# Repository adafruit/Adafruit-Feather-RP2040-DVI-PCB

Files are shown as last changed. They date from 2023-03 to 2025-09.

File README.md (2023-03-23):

## Adafruit Feather RP2040 DVI PCB

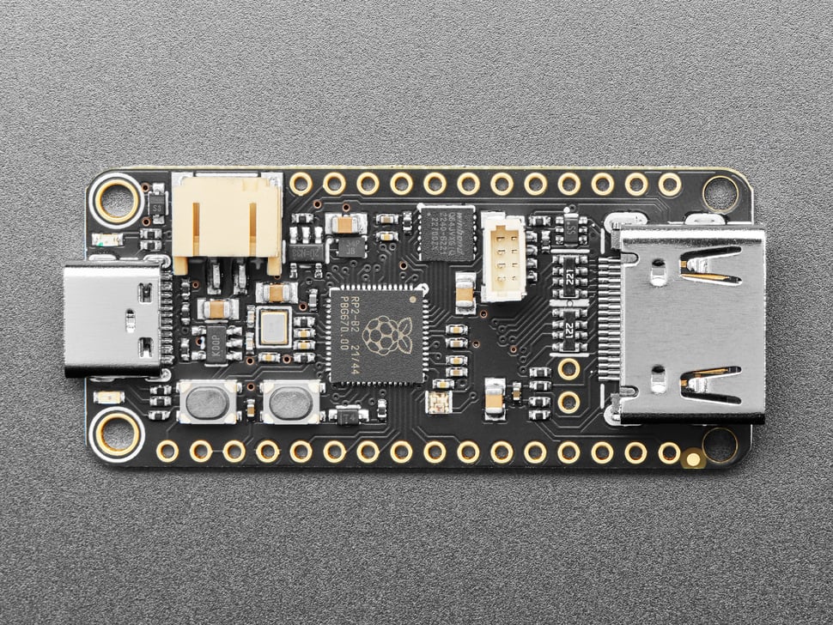
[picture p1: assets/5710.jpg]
<a href="http://www.adafruit.com/products/5710"><br/>
Click here to purchase one from the Adafruit shop</a>

PCB files for the Adafruit Feather RP2040 DVI. 

Format is EagleCAD schematic and board layout
* https://www.adafruit.com/product/5710

### Description

Wouldn't it be cool if you could display images and graphics from a microcontroller directly to an HDMI monitor or television? We think so! So we designed this RP2040 Feather that has a digital video output (a.k.a DVI) that will work with any HDMI monitor or display. Note it doesn't do audio, just graphics!

It's kinda like we took our RP2040 Feather and DVI Breakout board and glued them together. You get all the pins for use on the Feather, the Lipoly battery support, USB C power / data, onboard NeoPixel, 8MB of FLASH for storing code and files, and then with the 8 unused pins, a DVI output that can be used with the PicoDVI library in Arduino or Pico SDK (note we don't have Circuitpython support for DVI output at this time)

In Arduino, which is what we recommend, we use our fork of PicoDVI to create an internal framebuffer of 320x240 or 400x240 16-bit pixels that is then continuously blitted out as pixel-doubled 640x480 or 800x480 digital video. Whatever you 'draw' to the internal memory framebuffer appears instantly on the digital display in crisp color. Since the library is a subclass of AdafruitGFX, it'll be familiar to folks who have used our TFT or OLED displays before.

Note that the DVI video generation uses one full core, both PIOs, and 150K (320x240) or 190K (400x240) of SRAM. It's kinda maxed out so be aware of the remaining resource limitations.

We also connected the HDMI-connectors I2C pins to the SDA/SCL of the Feather (through a safe level shifter) so you can read the EDID EEPROM of displays, and have broken out the CEC and Utility pads. The Hot Plug Detect pin is also available on the very end of the 16-pin header. Read this pin to know when a display has been connected!

### License

Adafruit invests time and resources providing this open source design, please support Adafruit and open-source hardware by purchasing products from [Adafruit](https://www.adafruit.com)!

Designed by Limor Fried/Ladyada for Adafruit Industries.

Creative Commons Attribution/Share-Alike, all text above must be included in any redistribution. 
See license.txt for additional details.

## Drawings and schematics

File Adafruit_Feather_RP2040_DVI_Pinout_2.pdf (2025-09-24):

# Adafruit Feather RP2040 DVI

# https://www.adafruit.com/product/5710

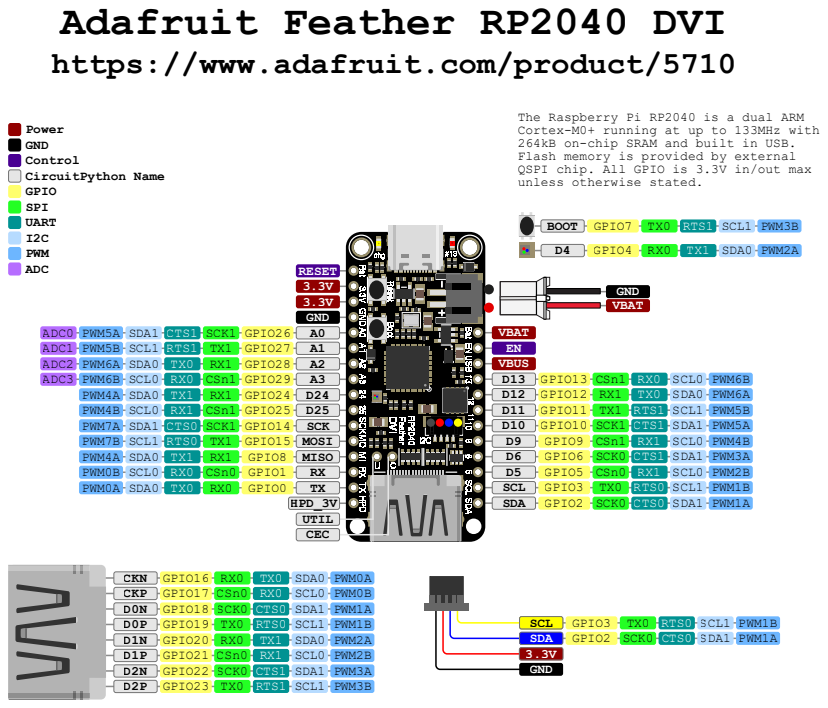
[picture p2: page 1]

The Raspberry Pi RP2040 is a dual ARM
Cortex-M0+ running at up to 133MHz with
264kB on-chip SRAM and built in USB.
Flash memory is provided by external
QSPI chip. All GPIO is 3.3V in/out max
unless otherwise stated.

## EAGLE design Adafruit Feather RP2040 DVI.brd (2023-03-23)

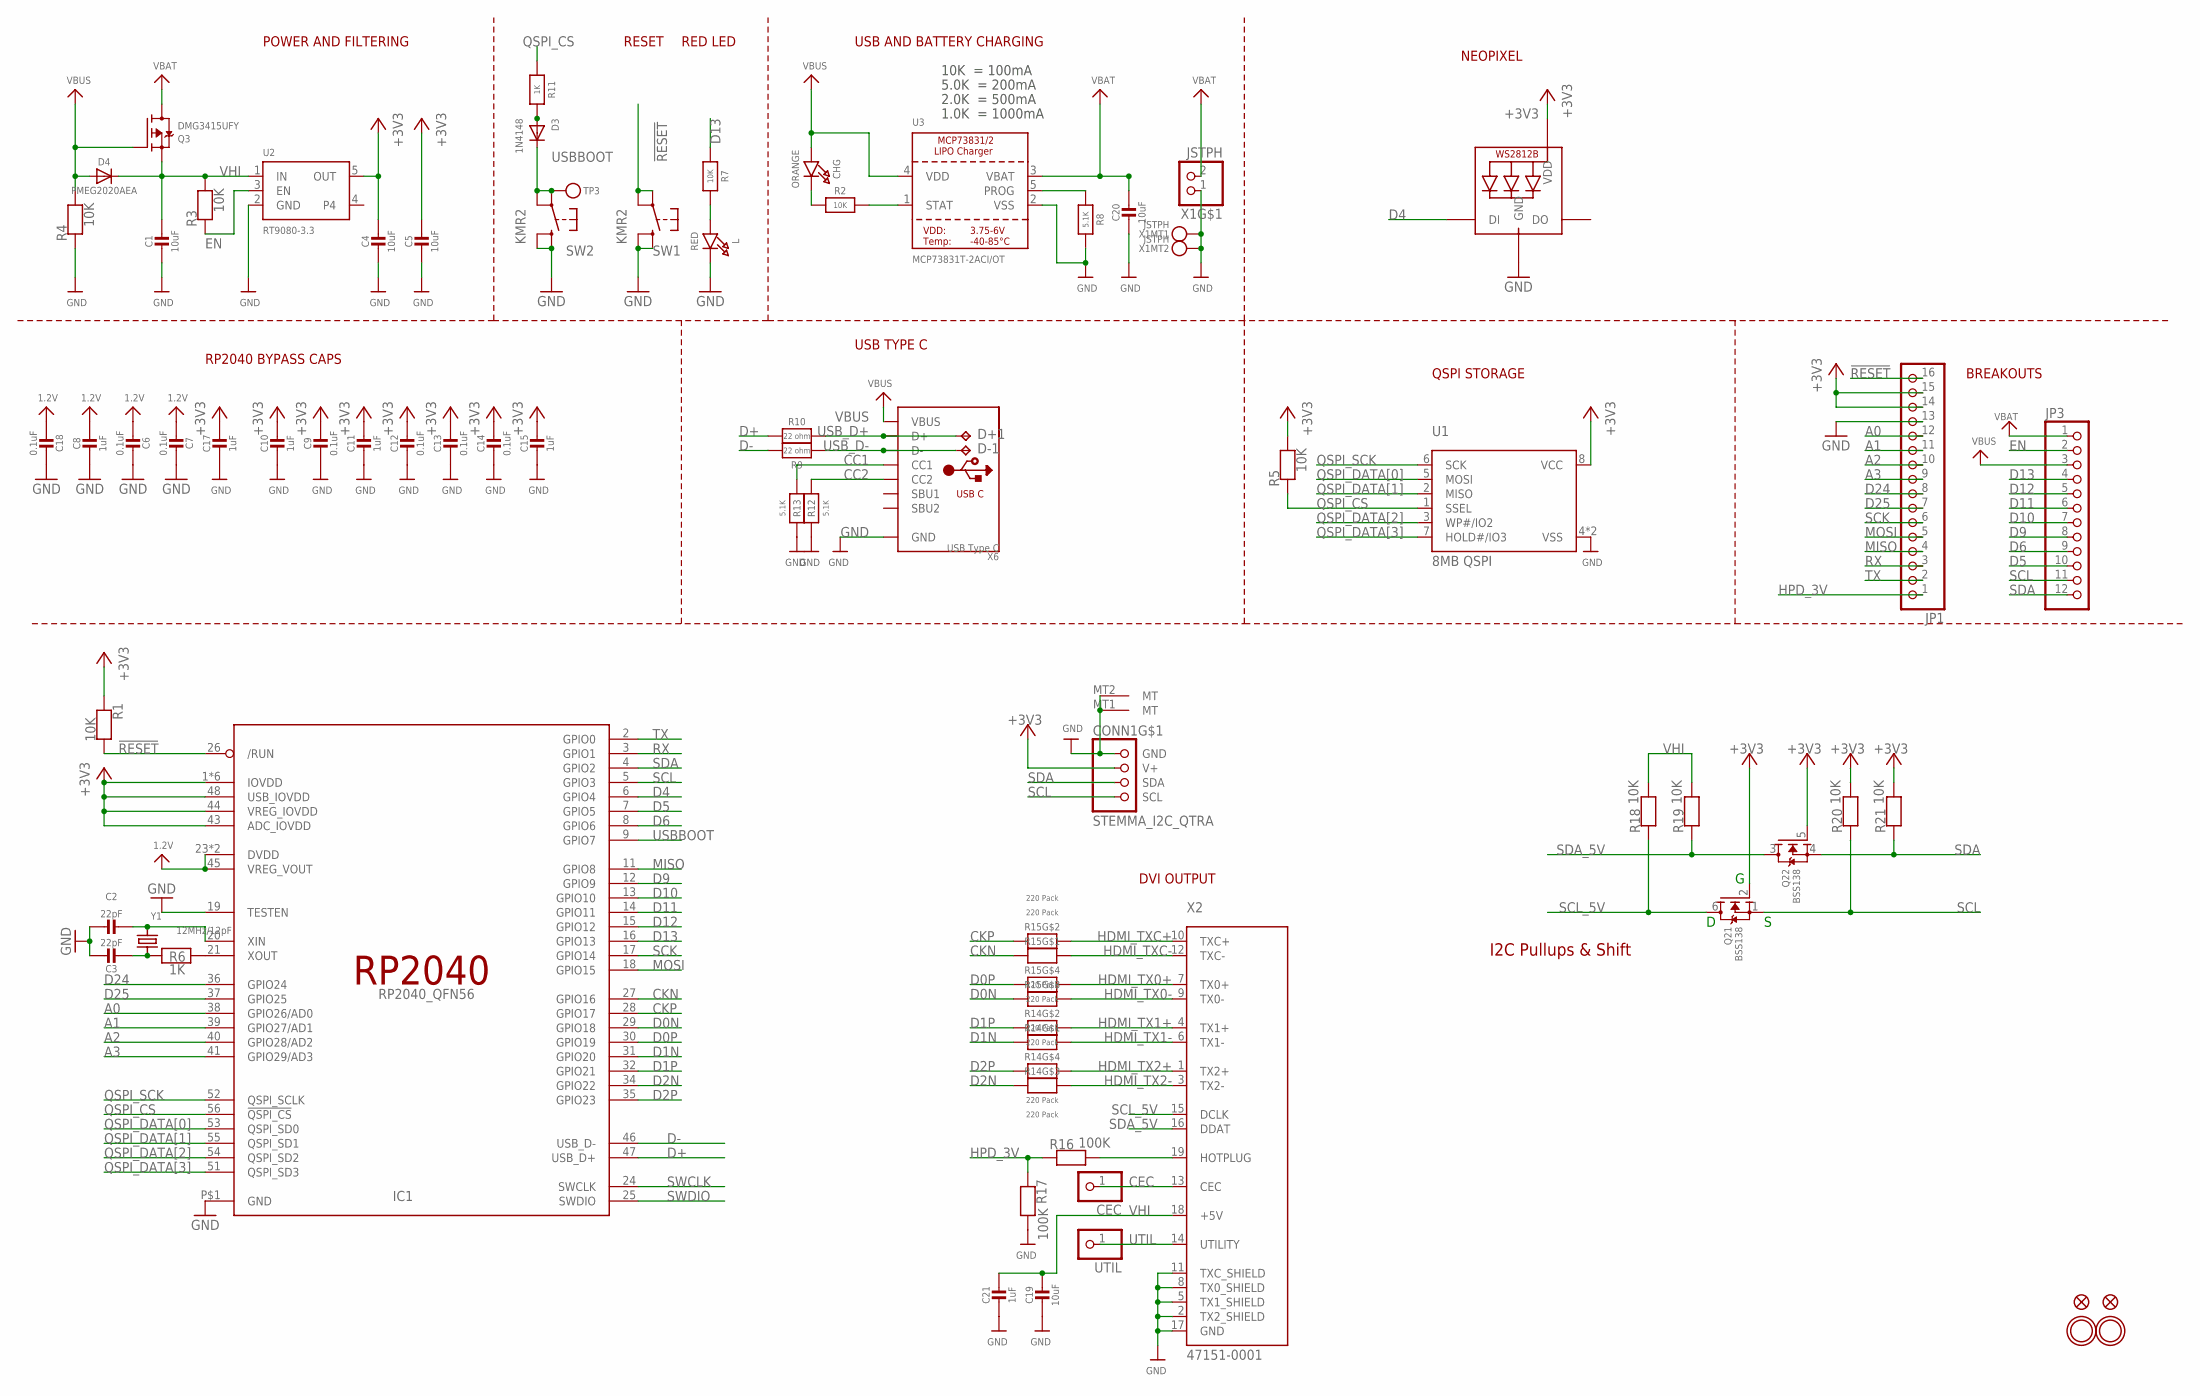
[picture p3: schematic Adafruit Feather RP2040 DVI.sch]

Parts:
C1, C4, C5, C19, C20: 10uF; 0805-NO
C2, C3: 22pF; _0402NO
C6, C7, C9, C12, C13, C14, C18: 0.1uF; _0402NO
C8, C10, C11, C15, C17, C21: 1uF; _0402NO
CEC: HEADER-1X1ROUND; 1X01_ROUND
CHG: ORANGE; CHIPLED_0603_NOOUTLINE
CONN1: STEMMA_I2C_QTRA; JST_SH4_RA
D3: 1N4148; SOD-323F
D4: PMEG2020AEA; SOD-323F
D+1: TPB1,27; B1,27
D-1: TPB1,27; B1,27
IC1: RP2040_QFN56; QFN56_7MM_REDUCEDEPAD
JP1: HEADER-1X16ROUND; 1X16_ROUND
JP3: HEADER-1X12; 1X12_ROUND
L: RED; CHIPLED_0603_NOOUTLINE
LED1: WS2812B_SK6805_1515; SK6805_1515
Q2: BSS138; SOT363
Q3: DMG3415UFY; DFN2015-3
R1, R2, R3, R4, R5, R7, R18, R19, R20, R21: 10K; _0402NO
R6, R11: 1K; _0402NO
R8, R12, R13: 5.1K; _0402NO
R9, R10: 22 ohm; _0402NO
R14, R15: 220 Pack; RESPACK_4X0603
R16, R17: 100K; _0402NO
SW1, SW2: KMR2; BTN_RKB2_4.6X2.8
TP3: TESTPOINTROUND1.5MMNO; TESTPOINT_ROUND_1.5MM_NO
U1: 8MB QSPI; USON8_4X4
U2: RT9080-3.3; SOT23-5; JLC_ROTATION 0
U3: MCP73831T-2ACI/OT; SOT23-5
U$31, U$32: MOUNTINGHOLE2.5; MOUNTINGHOLE_2.5_PLATED
U$34, U$35: FIDUCIAL_1MM
UTIL: HEADER-1X1ROUND; 1X01_ROUND
X1: JSTPH; JSTPH2_BATT
X2: 47151-0001; HDMI_MOLEX_47151-0001
X6: USB Type C; USB_C_CUSB31-CFM2AX-01-X
Y1: 12MHz/12pF; CRYSTAL_2.5X2

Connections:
1.2V: C6.2, C7.2, C8.1, C18.2, IC1.23 (DVDD), IC1.45 (VREG_VOUT), IC1.50 (DVDD)
!RESET: IC1.26 (/RUN), JP1.16, R1.2, SW1.A, SW1.A' (P1)
+3V3: C4.1, C5.1, C9.1, C10.1, C11.1, C12.1, C13.1, C14.1, C15.1, C17.1, CONN1.2 (V+), IC1.1 (IOVDD), IC1.10 (IOVDD), IC1.22 (IOVDD), IC1.33 (IOVDD), IC1.42 (IOVDD), IC1.43 (ADC_IOVDD), IC1.44 (VREG_IOVDD), IC1.48 (USB_IOVDD), IC1.49 (IOVDD), JP1.14, JP1.15, LED1.2 (VDD), Q2.2 (G), Q2.5 (G), R1.1, R5.2, R20.2, R21.2, U1.8 (VCC), U2.5 (OUT)
A0: IC1.38 (GPIO26/AD0), JP1.12
A1: IC1.39 (GPIO27/AD1), JP1.11
A2: IC1.40 (GPIO28/AD2), JP1.10
A3: IC1.41 (GPIO29/AD3), JP1.9
CC1: R13.2, X6.A5 (CC1)
CC2: R12.2, X6.B5 (CC2)
CEC: CEC.1, X2.13 (CEC)
CKN: IC1.27 (GPIO16), R15.8 (2)
CKP: IC1.28 (GPIO17), R15.7 (2)
D0N: IC1.29 (GPIO18), R15.6 (2)
D0P: IC1.30 (GPIO19), R15.5 (2)
D1N: IC1.31 (GPIO20), R14.8 (2)
D1P: IC1.32 (GPIO21), R14.7 (2)
D2N: IC1.34 (GPIO22), R14.6 (2)
D2P: IC1.35 (GPIO23), R14.5 (2)
D4: IC1.6 (GPIO4), LED1.1 (DI)
D5: IC1.7 (GPIO5), JP3.10
D6: IC1.8 (GPIO6), JP3.9
D9: IC1.12 (GPIO9), JP3.8
D10: IC1.13 (GPIO10), JP3.7
D11: IC1.14 (GPIO11), JP3.6
D12: IC1.15 (GPIO12), JP3.5
D13: IC1.16 (GPIO13), JP3.4, R7.1
D24: IC1.36 (GPIO24), JP1.8
D25: IC1.37 (GPIO25), JP1.7
D+: IC1.47 (USB_D+), R10.2
D-: IC1.46 (USB_D-), R9.2
EN: JP3.2, R3.1, U2.3 (EN)
GND: C1.2, C2.1, C3.1, C4.2, C5.2, C6.1, C7.1, C8.2, C9.2, C10.2, C11.2, C12.2, C13.2, C14.2, C15.2, C17.2, C18.1, C19.2, C20.2, C21.2, CONN1.1 (GND), CONN1.MT1 (MT), CONN1.MT2 (MT), IC1.19 (TESTEN), IC1.P$1 (GND), JP1.13, L.C, LED1.4 (GND), R4.1, R8.2, R12.1, R13.1, R17.2, SW1.B (S), SW1.B' (S1), SW2.B (S), SW2.B' (S1), U1.4 (VSS), U1.PAD (VSS), U2.2 (GND), U3.2 (VSS), X1.1, X1.NC1, X1.NC2, X2.2 (TX2_SHIELD), X2.5 (TX1_SHIELD), X2.8 (TX0_SHIELD), X2.11 (TXC_SHIELD), X2.17 (GND), X2.P$1 (GND), X2.P$2 (GND), X2.P$3 (GND), X2.P$4 (GND), X6.A1B12 (GND), X6.B1A12 (GND)
HDMI_TX0+: R15.4 (1), X2.7 (TX0+)
HDMI_TX0-: R15.3 (1), X2.9 (TX0-)
HDMI_TX1+: R14.2 (1), X2.4 (TX1+)
HDMI_TX1-: R14.1, X2.6 (TX1-)
HDMI_TX2+: R14.4 (1), X2.1 (TX2+)
HDMI_TX2-: R14.3 (1), X2.3 (TX2-)
HDMI_TXC+: R15.2 (1), X2.10 (TXC+)
HDMI_TXC-: R15.1, X2.12 (TXC-)
HPD: R16.2, X2.19 (HOTPLUG)
HPD_3V: JP1.1, R16.1, R17.1
MISO: IC1.11 (GPIO8), JP1.4
MOSI: IC1.18 (GPIO15), JP1.5
unnamed: CHG.C, R2.1
unnamed: L.A, R7.2
unnamed: R2.2, U3.1 (STAT)
unnamed: R8.1, U3.5 (PROG)
unnamed: C2.2, IC1.20 (XIN), Y1.3 (2)
unnamed: C3.2, R6.1, Y1.1
unnamed: IC1.21 (XOUT), R6.2
unnamed: D3.A, R11.2
QSPI_CS: IC1.56 (!QSPI_CS), R5.1, R11.1, U1.1 (SSEL)
QSPI_DATA[0]: IC1.53 (QSPI_SD0), U1.5 (MOSI)
QSPI_DATA[1]: IC1.55 (QSPI_SD1), U1.2 (MISO)
QSPI_DATA[2]: IC1.54 (QSPI_SD2), U1.3 (WP#/IO2)
QSPI_DATA[3]: IC1.51 (QSPI_SD3), U1.7 (HOLD#/IO3)
QSPI_SCK: IC1.52 (QSPI_SCLK), U1.6 (SCK)
RX: IC1.3 (GPIO1), JP1.3
SCK: IC1.17 (GPIO14), JP1.6
SCL: CONN1.4 (SCL), IC1.5 (GPIO3), JP3.11, Q2.1 (S), R20.1
SCL_5V: Q2.6 (D), R18.1, X2.15 (DCLK)
SDA: CONN1.3 (SDA), IC1.4 (GPIO2), JP3.12, Q2.4 (S), R21.1
SDA_5V: Q2.3 (D), R19.1, X2.16 (DDAT)
SWCLK: IC1.24 (SWCLK)
SWDIO: IC1.25 (SWDIO)
TX: IC1.2 (GPIO0), JP1.2
USBBOOT: D3.C, IC1.9 (GPIO7), SW2.A, SW2.A' (P1), TP3.P$1
USB_D+: D+1.TP, R10.1, X6.A6 (D+), X6.B6 (D+)
USB_D-: D-1.TP, R9.1, X6.A7 (D-), X6.B7 (D-)
UTIL: UTIL.1, X2.14 (UTILITY)
VBAT: C20.1, JP3.1, Q3.3 (D), U3.3 (VBAT), X1.2
VBUS: CHG.A, D4.A, JP3.3, Q3.1 (G), R4.2, U3.4 (VDD), X6.A4B9 (VBUS), X6.B4A9 (VBUS)
VHI: C1.1, C19.1, C21.1, D4.C, Q3.2 (S), R3.2, R18.2, R19.2, U2.1 (IN), X2.18 (+5V)

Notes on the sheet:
POWER AND FILTERING
RESET
10K = 100mA
5.0K = 200mA
2.0K = 500mA
1.0K = 1000mA
USB AND BATTERY CHARGING
BREAKOUTS
RED LED
DVI OUTPUT
RP2040 BYPASS CAPS
USB TYPE C
QSPI STORAGE
NEOPIXEL
I2C Pullups & Shift

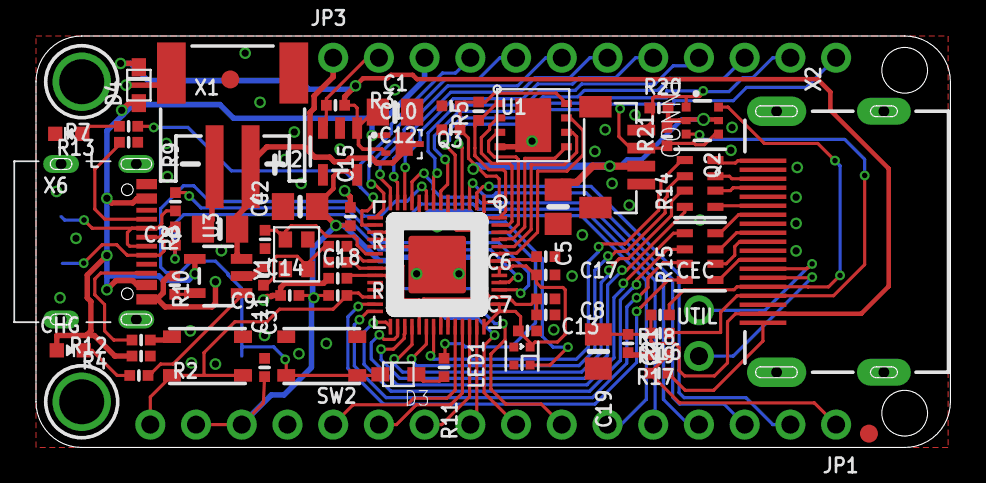
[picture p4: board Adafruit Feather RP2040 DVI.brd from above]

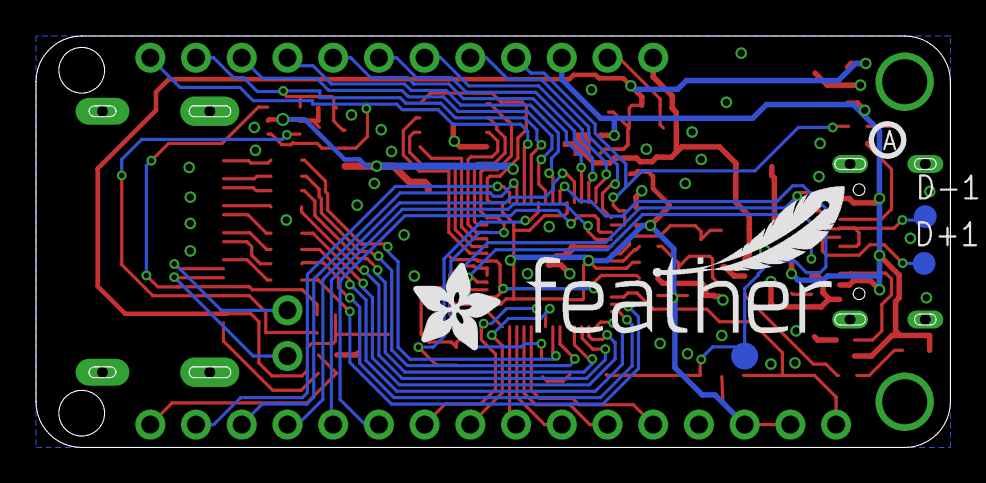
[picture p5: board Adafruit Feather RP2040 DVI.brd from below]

Board: 2 copper layers, 50.8 x 22.9 mm, 141 parts (38 on the bottom side), 72 nets.

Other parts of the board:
PLABEL0: PLABEL0
PLABEL1: PLABEL1
PLABEL2: PLABEL2
PLABEL3: PLABEL3
PLABEL4: PLABEL4
PLABEL5: PLABEL5
PLABEL6: PLABEL6
PLABEL7: PLABEL7
PLABEL8: PLABEL8
PLABEL9: PLABEL9
PLABEL10: PLABEL10
PLABEL11: PLABEL11
PLABEL12: PLABEL12
PLABEL13: PLABEL13
PLABEL14: PLABEL14
PLABEL15: PLABEL15
PLABEL16: PLABEL16
PLABEL17: PLABEL17
PLABEL18: PLABEL18
PLABEL19: PLABEL19
PLABEL20: PLABEL20
PLABEL21: PLABEL21
PLABEL22: PLABEL22
PLABEL23: PLABEL23
PLABEL24: PLABEL24
PLABEL25: PLABEL25
PLABEL26: PLABEL26
PLABEL27: PLABEL27
PLABEL28: PLABEL28
PLABEL29: PLABEL29
PLABEL30: PLABEL30
PLABEL31: PLABEL31
PLABEL32: PLABEL32
PLABEL33: PLABEL33
PLABEL34: PLABEL34
PLABEL35: PLABEL35
PLABEL36: PLABEL36
PLABEL37: PLABEL37
PLABEL38: PLABEL38
PLABEL39: PLABEL39
PLABEL40: PLABEL40
PLABEL41: PLABEL41
PLABEL42: PLABEL42
PLABEL43: PLABEL43
PLABEL44: PLABEL44
PLABEL45: PLABEL45
PLABEL46: PLABEL46
PLABEL47: PLABEL47
PLABEL48: PLABEL48
PLABEL49: PLABEL49
PLABEL50: PLABEL50
PLABEL51: PLABEL51
PLABEL52: PLABEL52
PLABEL53: PLABEL53
PLABEL54: PLABEL54
PLABEL55: PLABEL55
PLABEL56: PLABEL56
PLABEL57: PLABEL57
PLABEL58: PLABEL58
PLABEL59: PLABEL59
PLABEL60: PLABEL60
PLABEL61: PLABEL61
PLABEL62: PLABEL62
PLABEL63: PLABEL63
PLABEL64: PLABEL64
PLABEL65: PLABEL65
PLABEL66: PLABEL66
PLABEL67: PLABEL67
U$13: PCBFEAT-REV-040
U$42: FEATHERLOGO_MED
U$46: ADAFRUIT_5MM

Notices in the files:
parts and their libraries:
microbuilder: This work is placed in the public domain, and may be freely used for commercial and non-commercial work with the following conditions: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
